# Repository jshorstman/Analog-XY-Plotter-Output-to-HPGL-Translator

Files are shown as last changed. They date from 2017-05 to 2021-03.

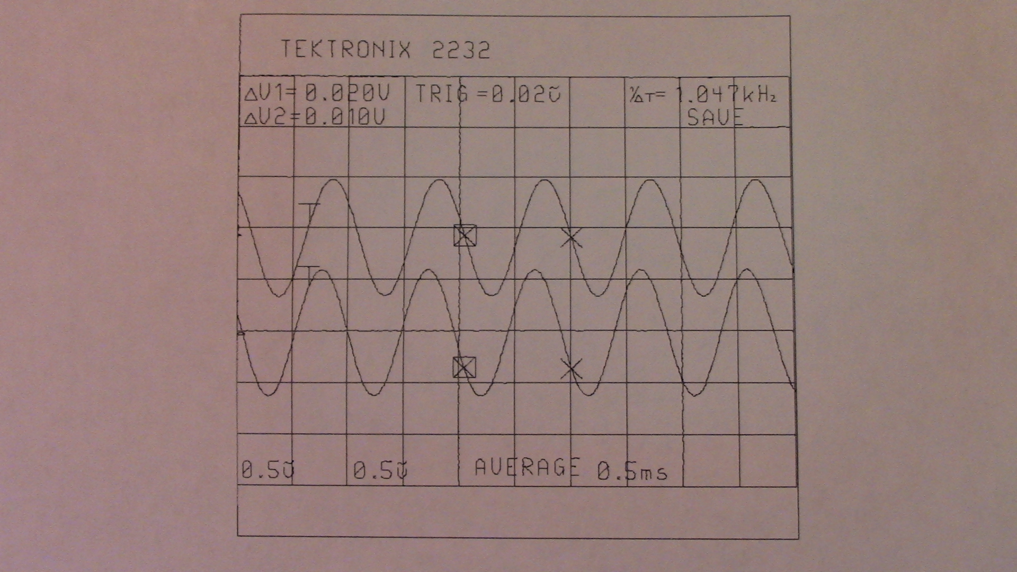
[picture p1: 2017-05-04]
Photos/Sample Plot Printout.JPG

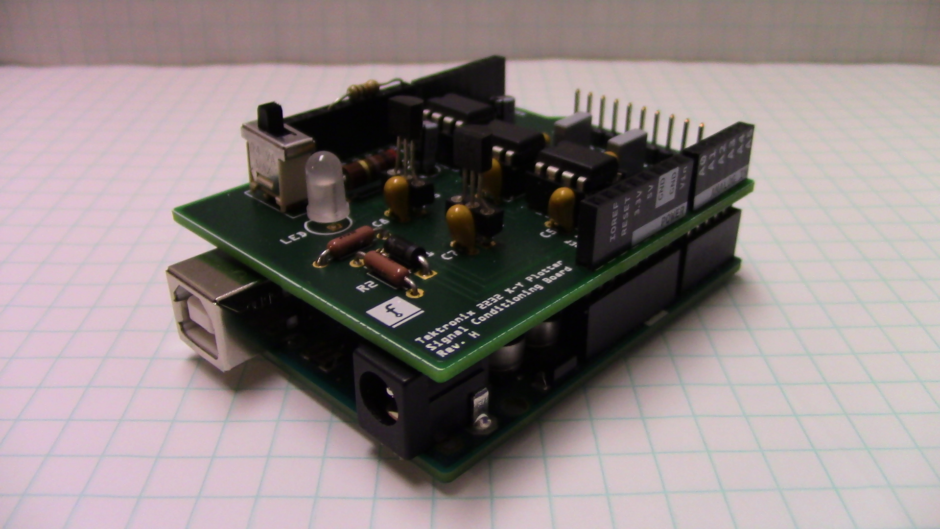
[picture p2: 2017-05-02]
Photos/IMG_0015.JPG

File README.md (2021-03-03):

# Analog-XY-Plotter-Output-to-HPGL-Translator
The Translator will continually sample the X and Y analog voltages from an oscilloscope's pen plotter output port, digitize them, and package the values into a series of plain text HP-GL plotter commands, which are output via a USB port to a file on a PC. The HP-GL file can be processed into a display image by any commonly available plotter emulator application, such as SPLOT (http://www.swplot.com/splot.htm).<BR>
Read all about it in the 'Documentation/Translator Description.docx' document.<BR>
See the demo video on YouTube; https://youtu.be/DhNy6BU84X4

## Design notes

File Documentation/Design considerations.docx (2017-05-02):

Purpose:

Convert the analog voltage X-Y pen plotter output of the Tektronix 2232 oscilloscope to a series of HP-GL plotter graphics commands that are serailly output, via USB, to a PC file. The HPGL file can be processed by any print capturing application (like PrintCapture (http://www.printcapture.com/)) and displayed as a plot image.

(HP-GL: Hewlett-Packard Graphics Language (http://en.wikipedia.org/wiki/HPGL))

Subsystems:

1. Arduino UNO (https://www.arduino.cc/en/Main/ArduinoBoardUno) for the ADC conversions, digital filtering, assembly of HPGL commands and serial output.
2. Arduino Proto Shield (https://store.arduino.cc/usa/arduino/arduino-shields/proto-shield-rev3-uno-size) board for signal conditioning (voltage translation), voltage reference and power monitoring.

Design considerations:

1. Use Arduino UNO because it's the most common beginners model and can support an Arduino Proto Shield.
2. Power. The 5V voltage reference, and the summing amps, which output up to 5 volts, require at least 2 volts headroom. Therefore, cannot rely on the USB port as power source. Use 9V external walwart which gives plenty of headroom since this power supply, when plugged in, will also provide power to the Arduino board.
3. Scope outputs ±2.5 volts on X and Y. Arduino UNO analog pins accept only 0 to 5 volts. Need to translate ±2.5v to 0-5v. Use Unity gain summing amplifiers with a 2.5V voltage reference.
4. Need an indication that there is not sufficent power should an external power supply not be used. These ICs cannot operate on ~5V USB power. Add a bi-color red/green LED as a 'Go-No Go' indicator of sufficient power. A voltage divider network to divide 9V power down to 5V for Arduino analog input pin. Also, need schottky protection diode to proect Arduino pin for power supplies over 9 volts.
5. Summing amps must provide down to 0 volts (gnd). Too close to the rail for single-sided powered amps. Need bi-polar power, say ±9V. Use charge pump voltage converter to create -9 volts for the summing amps. Plenty of headroom. Minimum parts count; 2 caps.
6. Current draw from two summing amps will drag down the negative voltage of the voltage converter. Calculation shows voltage dragged down to ~-8.5 volts. Plenty of headroom left.
7. Precision 2.5V voltage reference must drive inputs of the two summing amps.
8. Use a precision 5V voltage reference for the Arduino AREF pin. Don't want to rely on Arduino voltage regulator as a reliable voltage reference.
9. A switch to start and stop the data stream. Some HP-GL initialization commands and finalization commands must be output.
10. Of course, power supply bypass caps for all ICs.
11. Measured maximum slew rate of scope plotter voltages is ~3v/sec. Adjust sampling rate accordingly so as not to have too many redundant plot points (current sampling rate is 615 points/sec).
12. Filtering applied dither: The analog X Y voltages of the Tektronix pen plotter output have copious added dither. That's fine for shaking loose the mecanical plotter arms and is filtered out by the mass inertia of the mechanical arms. BUT, the 10-bit ADC can pick up the dithered voltage at any instant in time. How to filter it out. A combination of analog and digital filtering.
  a. Analog: A 0.068µf (found by trial and error) capacitor to ground on the input couples with the 2KΩ output resistance of the analog output amplifier of the scope to produce an RC low pass filter. That attenuates a lot of the high frequency components of the dithered waveform but it can go only so far before image quality is degraded.
  b. Digital: A moving average filter of n=8. This gets rid of the two LSBs of the ADC value since they're considered noise bits anyway. With n=16 it softens the corners too much in the image.
13. Connect Tektronix shield ground to Arduino ground? Nah, signal ground is good enough, avoids ground loops.
14. Copper ground fill on circuit board.

References:

- Atmel ATmega328/P 8-bit AVR Microcontroller Datasheet.
- Arduino Programming Nootebook by Brian W. Evans.
- Arduino Uno Rev3 Schematic
- Tektronix 2232 Digital Storage Oscilloscope User Manual, 070-7066-01
- Tektronix 2232 Digital Storage Oscilloscope Service Manual, 070-7067-01
- The HP-GL/2 and HP RTL Reference Guide, A Handbook for Program Developers, 5961-3526

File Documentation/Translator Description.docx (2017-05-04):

What it is:

An analog X-Y pen plotter output to HP-GL translator. (Hewlett-Packard Graphics Language (http://en.wikipedia.org/wiki/HPGL)

What it does:

Some measurement devices, like the Tektronix 2232 Digital Storage Oscilloscope, have an analog X-Y pen plotter output port so that the display image can be captured to an analog X-Y pen plotter or recorder. See oscilloscope display, below.

The problem is one wishes to capture the display image in digital form onto a modern day personal computer, since analog pen plotters are virtually extinct. PC images can be pasted directly into documents.

The 'Analog X-Y Pen Plotter Output To HP-GL Translator' will continually sample the X and Y analog voltages from the plotter port, digitize them, and package the values into a series of plain text HP-GL plotter commands, which are output via a USB port to a file on a PC. The HP-GL file can be processed into a display image by any commonly available plotter emulator application, such as PrintCapture (http://www.printcapture.com). See actual plot image, below.

What it's made of:

1. Arduino UNO (http://www.arduino.org/products/boards/arduino-uno) for the ADC conversions, digital filtering, assembly of HP-GL commands and serial output.
2. Arduino 'Shield' type board for signal conditioning (voltage translation), voltage reference and power monitoring. See schematic and boards, below.
3. DB9 cable for connection to the oscilloscope plotter port. See Auxiliary Connector, below.
4. USB cable between Arduino UNO and PC.
5. 9VDC AC adapter (a wall wart).

What's on the Arduino shield board:

The Arduino shield board contains circuitry comprised of (see schematic);

1. Two (2) precision, unity-gain differential amplifiers (wired as summing amps) to translate the ±2.5V analog X and Y voltages into 0 to 5V for the Arduino analog pins. U2, U3
2. A 'charge pump' voltage converter to convert 9VDC to ±9VDC to power the amplifiers. U1, C1, C2
3. A precision 2.50V voltage reference to the amplifiers for the voltage translation. U4
4. A precision 5.00V voltage reference to the Arduino AREF pin. U5
5. A voltage divider network so the 9V Vin can be reduced to 5V for the Arduino analog pin. A schottky diode protects the pin if a higher voltage power supply is used. R1, R2, D1
6. A bi-color red/green LED as a Go/No Go indicator that the 9V power supply is connected, or not. The Arduino sketch will stay in the setup() routine until a 9VDC, or greater, power supply is plugged into the Arduino UNO. These IC's cannot run accurately on the USB ~5V power! LED, R3
7. A slide switch to start the data stream and stop it when the plot is completed. S1
8. A pair of capacitors to filter the DAC dithering of the plotter port X and Y voltage signals. C9, C10
9. A 10-pin header for connection to the oscilloscope plotter port. J1

Operation:

1. Slide switch to OFF.
2. Connect Arduino via DB-9 connector to oscilloscope plotter port.
3. Connect Arduino USB to PC. Arduino powers up, LED is red.
4. Connect 9VDC power to Arduino. LED is green.
5. Launch listening application, like TeraTerm or PrintCapture. Ensure your application is set to the Arduino UNO COM port 6, 115200, 8, none, 1.
6. Slide switch to ON. (data stream commences)
7. Immediately press PLOT key on scope.
8. When scope plot completes immediately slide switch to OFF. (data stream halts)
9. Reset Arduino in order to start the next plot.

Example HP-GL (http://en.wikipedia.org/wiki/HP-GL) output to file:

IN;

PS8900,8900;

IP0,0,8900,8900;

SC0,250,0,1023,1;

PU; // Pen Up

SP1;

PA77,984; // Plot Absolute to (77,984)

... // more data points (PA) every 1.6 milliseconds

PD; // Pen Down

PA53,92;

... // more data points (PA) every 1.6 milliseconds

PU;

SP;

IN;

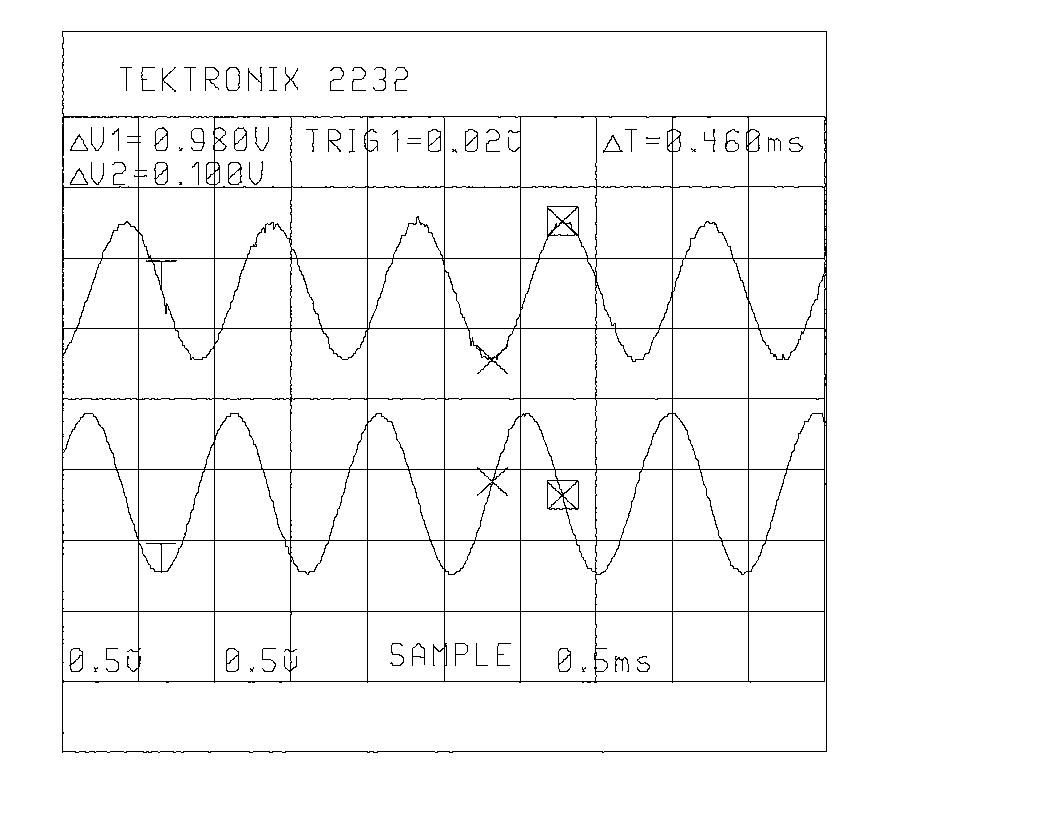
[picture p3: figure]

Actual plot image from an HP-GL file created by the Translator of a Tektronix 2232 oscilloscope display. Image created by PrintCapture (http://www.printcapture.com).

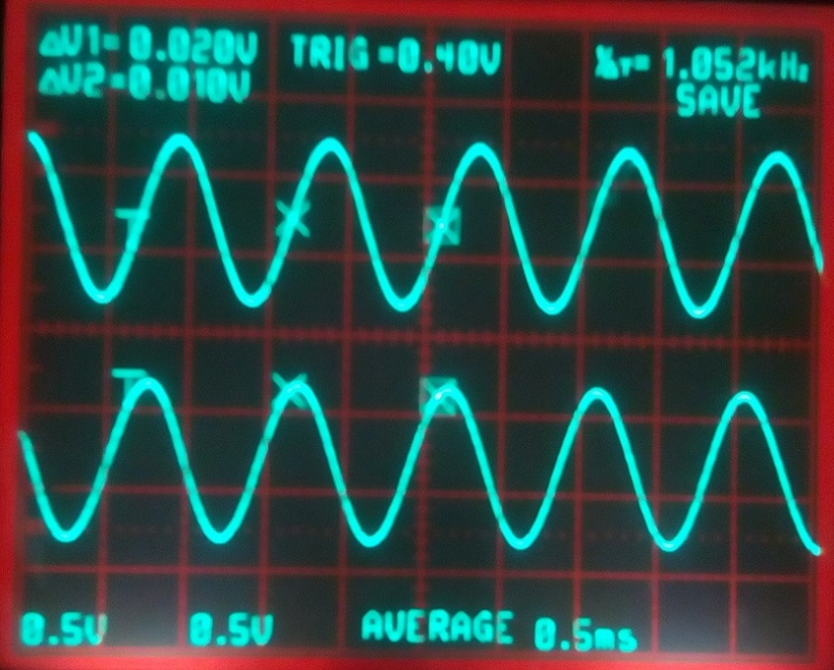
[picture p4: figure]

Actual Tektronix 2232 oscilloscope display.

Schematic:

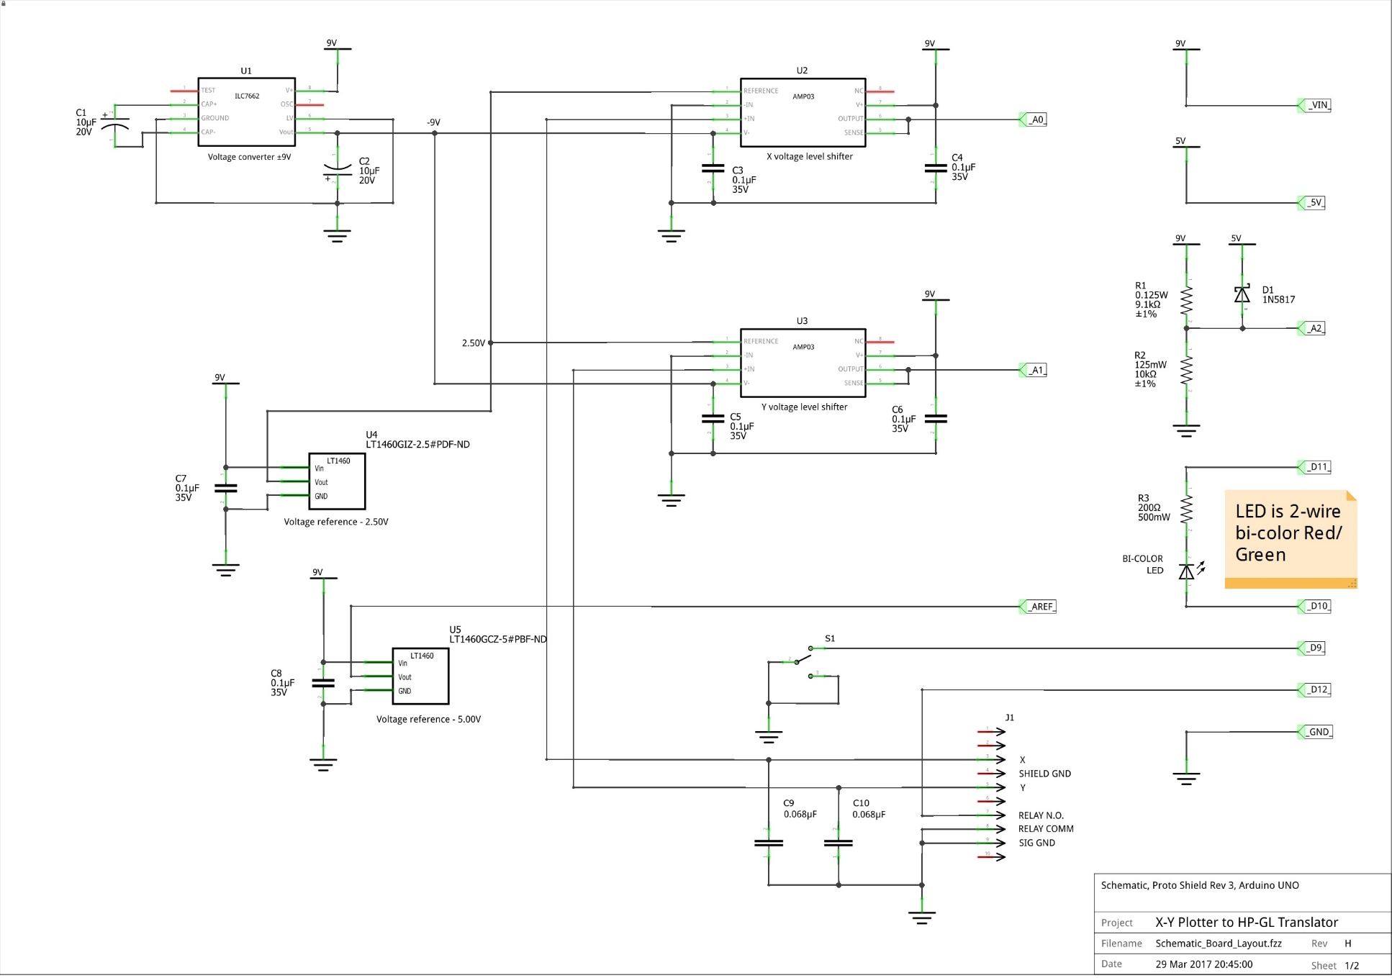
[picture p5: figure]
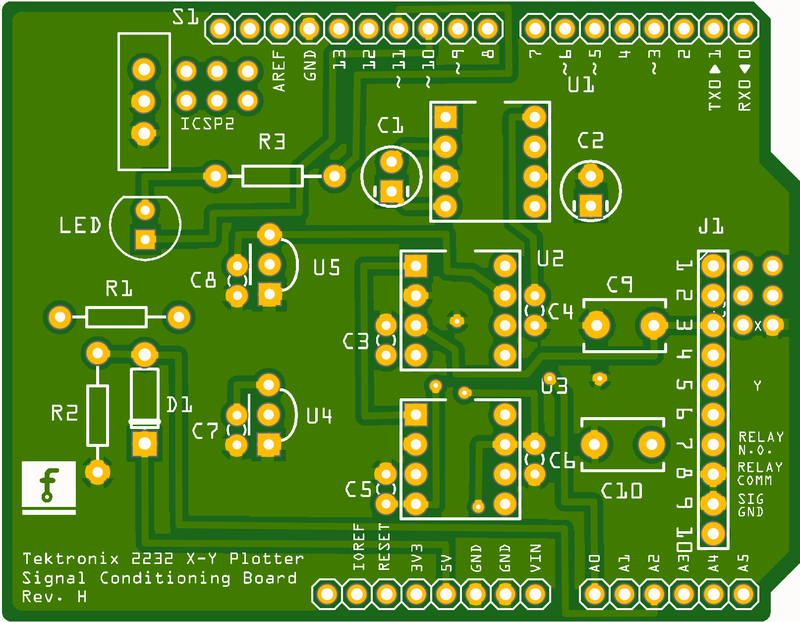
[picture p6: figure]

Arduino shield board front

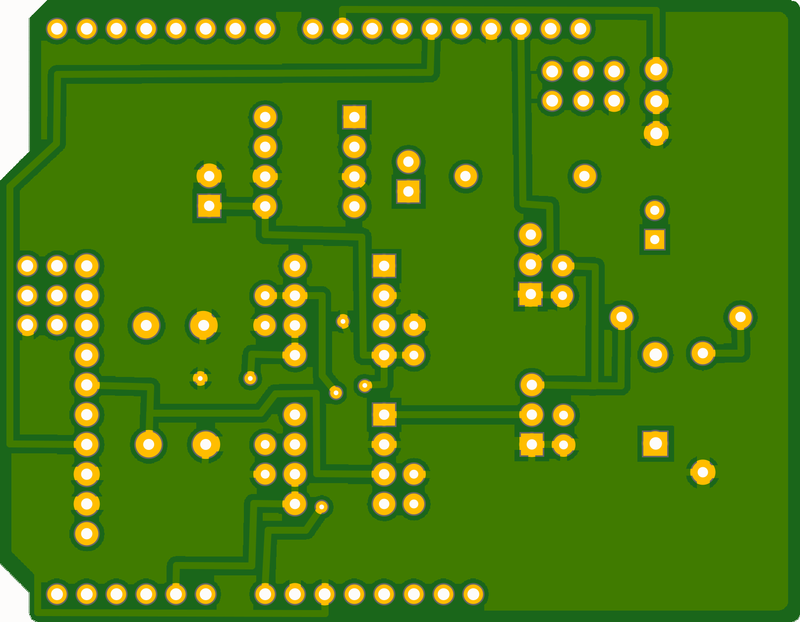
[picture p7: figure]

Arduino shield board back

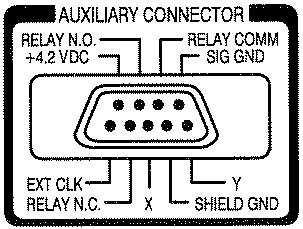
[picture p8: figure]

Tektronix Auxiliary Connector for X-Y plotter. Relay is for pen up/down

Arduino Sketch:

/*

****************************************************************************************|

* Tektronix 2232 Digital Storage Oscilloscope analog X-Y pen plotter to HP-GL

* translator. (Hewlett-Packard Graphics Language http://en.wikipedia.org/wiki/HPGL)

*

* John Horstman

* 3/19/2017 Rev H

*

* This sketch continuously reads the X and Y analog pen plotter voltages, and the

* pen up/down signal, and packages the ADC values in successive HP-GL commands. The

* commands can be serially output to a file, via TeraTerm, or to a plotter application

* like PrintCapture at http://www.printcapture.com/.

*

* The HP-GL commands used in this sketch are:

* IN; Initialize

* PS: Plot size

* IP; Input P1 & P2

* SC; Scale

* SP; Select pen

* PU; Pen UP

* PD; Pen DOWN

* PA; Plot Absolute

*

* Example HPGL output of this sketch:

* IN;

* PS8900,8900;

* IP0,0,8900,8900;

* SC0,250,0,1023,1;

* PU;

* SP1;

* PA77,984;

* ... // data points every 1.6 milliseconds

* PD;

* PA53,92;

* ...

* PU;

* SP;

* IN;

*

* This sketch is for Arduino UNO with Proto Shield. The Proto Shield contains signal

* conditioning circuitry comprised of;

* 1. Two (2) precision, unity-gain differential amplifiers (wired as summing amps)

* to translate the Â±2.5V analog X and Y voltages into 0 to 5V for the Arduino analog

* pins.

* 2. A 'charge pump' voltage converter to convert 9VDC to Â±9VDC to power the amplifiers.

* 3. A precision 2.50V voltage reference to the amplifiers for the voltage translation.

* 4. A precision 5.00V voltage reference to the Arduino AREF pin.

* 5. A voltage divider network so the 9V Vin can be reduced to 5V for the Arduino

* analog pin. A schottky diode protects the pin if a higher voltage power supply

* is used.

* 6. A bi-color red/green LED as a Go/No Go indicator that the 9V power supply

* is connected, or not. This sketch will stay in the setup() routine until a

* 9VDC, or greater, power supply is plugged in to the Arduino. These IC's

* cannot run accurately on the USB ~5V power!

* 7. A slide switch to start the data stream and stop it when the plot is completed.

* 8. A pair of capacitors to filter the DAC dithering of the plotter X-Y voltage signals.

* 9. A 9-pin cable with DB-9 male connector for connection to the oscilloscope plotter

* port.

*

* Operation:

* Slide switch to OFF.

* Connect Arduino via DB-9 connector to oscilloscope plotter port.

* Connect Arduino USB to PC. Arduino powers up, LED is red.

* Connect 9VDC power to Arduino. LED is green.

* Launch listening application, like TeraTerm or PrintCapture. Ensure your application

* is set to the Arduino COM port 6, 115200, 8, none, 1.

* Slide switch to ON. (data stream commences)

* Immediately press PLOT key on scope.

* When scope plot completes immediately slide switch to OFF. (data stream halts)

* Reset Arduino in order to start the next plot.

****************************************************************************************|

*/

//#define __serial_plotter // uncomment to calibrate with Arduino Serial Plotter tool

//#define __dummy_data // uncomment to use dummy data for testing

// The pins

#define TestPin 8 // Digital pin 8

#define SwitchPin 9 // Digital pin 9

#define LEDGreenPin 10 // Digital pin 10

#define LEDRedPin 11 // Digital pin 11

#define PenInputPin 12 // Digital pin 12

#define IdleLED 13 // Digital pin 13

#define X_voltage 0 // Analog pin A0

#define Y_voltage 1 // Analog pin A1

#define VinVoltage 2 // Analog pin A2

// The numbers

unsigned long LoopTime; // Marker for loop() delay timer

unsigned int PenState = HIGH; // Default pen up

unsigned int OldPenState = PenState; //

const unsigned int numReadings = 8; // Must be a power of two so we can right shift later

unsigned int Xreadings[numReadings]; // Arrays for computing moving average for smoothing

unsigned int Yreadings[numReadings]; //

unsigned int Xtotal = numReadings * 511; // Arrays will be preloaded

unsigned int Ytotal = Xtotal; //

unsigned int readIndex = 0; //

const unsigned int dcXOffset = 0; //21; // Compensate for any DC offset. Adjust this to get approximately 511,511.

const unsigned int dcYOffset = 0; //23; //

// The strings

String ADCXStr; // ADC X counts string

String ADCYStr; // ADC Y counts string

String CmdStr; // HPGL command string

#ifdef __dummy_data

const float slew = 614.0; // max slew rate is 3.0 volts/second = 614 counts/second (@5 volts = 1023 counts)

const float Freq = (1.0/PI) * (slew / 1023.0); // This frequency sinusoidal will have that slew rate (at the zero crossing)

const float TWO_PI_F = 2.0 * PI * Freq;

#endif

/*

* The Setup ****************************************************************************|

*/

void setup() {

// Set I/O pins

pinMode(TestPin, OUTPUT); // timing test pin

pinMode(IdleLED, OUTPUT);

pinMode(LEDRedPin, OUTPUT);

pinMode(LEDGreenPin, OUTPUT);

pinMode(SwitchPin, INPUT_PULLUP);

pinMode(PenInputPin, INPUT_PULLUP); // Pen signal is from Normally Open (N.O.) relay contacts

analogReference(DEFAULT);

// Set LEDs

digitalWrite(IdleLED, HIGH); // Turn on 'idle' LED

digitalWrite(LEDRedPin, LOW); // Turn red/green LED off

digitalWrite(LEDGreenPin, LOW);

// initialize serial communication:

Serial.begin(115200);

// Check for 9V Vin external power, stay in setup() until 9V supply connected

/*

* Why 900 counts? To gaurantee that a 7.5 VDC±5% power pack will not trigger the

* 'Go' signal under maximal conditions:

* 7.5v+5%; R1Ω-1%; R2Ω+1%; USB 5v-5% (AREF); +3 counts (2 LSB ADC error)

*/

while (analogRead(VinVoltage) < 900) {

digitalWrite(LEDRedPin, HIGH); // Turn LED red (no-go)

digitalWrite(LEDGreenPin, LOW);

delay(100);

} // Wait here until user plugs in a 9VDC, or greater, power supply

// Vin OK, continue

digitalWrite(LEDRedPin, LOW); // Turn LED green (go)

digitalWrite(LEDGreenPin, HIGH);

//Wait here for switch to be switched on (ground the pin)

while (digitalRead(SwitchPin) == HIGH) {

delay(100);

}

// User is ready for data stream, let 'er rip!

analogReference(EXTERNAL); // External precision 5.00V reference

// Preset the averaging arrays

for (int thisReading = 0; thisReading < numReadings; thisReading++) {

Xreadings[thisReading] = 511;

Yreadings[thisReading] = 511;

}

digitalWrite(IdleLED, LOW); // turn off 'idle' LED, transmission will commence (TX LED will light)

// HP-GL plot header commands

Serial.println("IN;"); // Initialize

Serial.println("PS8900,8900;"); // Plot size; A-size

Serial.println("IP0,0,8900,8900;"); // Input Scaling Points P1 & P2; A-size drawing (8.5" x 11", less margins)

Serial.println("SC0,1023,0,1023,1;"); // Scale; Isotropic

//Serial.println("OH;"); // Output hard clip limits

//Serial.println("OP;"); // Output P1 & P2

Serial.println("PU;"); // Pun Up

Serial.println("SP1;"); // Select Pen 1

} // end setup

/*

* The Loop *****************************************************************************|

*/

void loop() {

LoopTime = micros(); // mark loop start

// Read X, Y and Pen signals as close together as possible and compute a moving average for smoothing

Xtotal -= Xreadings[readIndex]; // Subtract an old value from the total

Ytotal -= Yreadings[readIndex]; //

PenState = digitalRead(PenInputPin); // Read pen input; returns HIGH or LOW

Xreadings[readIndex] = analogRead(X_voltage) - dcXOffset; // compensate for dc offset

delayMicroseconds(16); // Delay two ADC clock cycles (there is less 'jitter' on the Y readings than for a one ADC clock cycle dalay, don't ask me why)

Yreadings[readIndex] = analogRead(Y_voltage) - dcYOffset;

Xtotal += Xreadings[readIndex]; // Add the new value to the total

Ytotal += Yreadings[readIndex++]; // Increment readIndex here

readIndex %= numReadings; // Wrap around readIndex here

ADCXStr = Xtotal >> 3; // Total divided by numReadings (and convert to string)

ADCYStr = Ytotal >> 3;

//

// If pen has changed state then output pen command

// Pen UP signal is HIGH (relay open, interanl pull up resistor), pen DOWN is LOW (relay closed to ground)

if (PenState != OldPenState) {

(PenState == HIGH) ? (CmdStr = "PU;") : (CmdStr = "PD;");

OldPenState = PenState; // Remember pen state

Serial.println(CmdStr);

}

#ifdef __dummy_data

// dummy data for now, plot a circle

float t = (float)millis() / 1000.0;

float arg = TWO_PI_F * t;

ADCXStr = int(511.5*cos(arg)+511.5);

ADCYStr = int(511.5*sin(arg)+511.5);

#endif

#ifdef __serial_plotter

int Pen;

(PenState == HIGH) ? Pen = 10 : Pen = 0; // View the Pen up/down signal

CmdStr = "1023 0 " + ADCXStr + " " + ADCYStr + " " + Pen; // 1023 0 prevents autoscaling

#else

// 'Plot Absolute' Ex: PA1023,250;

CmdStr = "PA" + ADCXStr + "," + ADCYStr + ";";

#endif

Serial.println(CmdStr);

// If switch went HIGH, output final commands, stop data stream, the plot is completed, wait here until RESET

if (digitalRead(SwitchPin) == HIGH) {

Serial.println("PU;");

Serial.println("SP;");

Serial.println("IN;");

while (true) { // wait here for RESET

// flash 'idle' LED to indicate need for reset

digitalWrite(IdleLED, HIGH);

delay(200);

digitalWrite(IdleLED, LOW);

delay(300);

}

}

//

/* Wait here for remainder of loop time.

* Full scale plot swing is 1023 counts in 1.667 seconds (5 volt full swing / 3.0 volts/second).

* So, no more than one plot command every 1.630ms is necessary (1.667/1023). ~614 samples/second.

*/

while (micros() - LoopTime < 1630) {;} // wait here for remainder of loop time

// Short (0.250Âµs) output pulse to test loop timing.

PORTB |= B1; PORTB ^= B1; // digitalWrite(TestPin, HIGH); digitalWrite(TestPin, LOW);

} // end loop

Part List:

Cost:

Arduino UNO (http://www.arduino.org/products/boards/arduino-uno) | $25
Arduino Proto Shield (http://www.arduino.org/products/shields/arduino-proto-shield) (needed for the headers only. I spun my own board) | $8
Parts (25) | $57
Board by Aiser (http://go.aisler.net/) (qty 3) | $34 (€31)
Total | $124 (€114)

References:

• Atmel ATmega328/P 8-bit AVR Microcontroller Datasheet.

• Arduino Programming Nootebook by Brian W. Evans.

• Arduino Uno Rev3 Schematic

• Tektronix 2232 Digital Storage Oscilloscope User Manual, 070-7066-01

• Tektronix 2232 Digital Storage Oscilloscope Service Manual, 070-7067-01

• The HP-GL/2 and HP RTL Reference Guide, A Handbook for Program Developers, 5961-3526

Analog X-Y Pen Plotter Output To HP-GL Translator http://github.com/jshorstman/Analog-XY-Plotter-Output-to-HPGL-Translator

Analog X-Y Pen Plotter Output To HP-GL Translator

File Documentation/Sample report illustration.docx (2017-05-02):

Lorem ipsum dolor sit amet, consectetur adipiscing elit. Vestibulum lorem ante, pulvinar sed mauris nec, efficitur pretium nisi. Mauris maximus magna eget consequat consequat. Nulla sit amet tortor sed nisi malesuada pharetra. Nulla vitae nibh libero. Aliquam erat volutpat. Donec fringilla sed velit in laoreet. Suspendisse lorem sapien, pretium at auctor sed, porttitor eget ex. Praesent id semper ligula, ac dignissim quam. Donec scelerisque posuere massa ac efficitur. Donec tristique ante a feugiat lobortis. Fusce at orci vel urna lobortis convallis. In iaculis varius porta.

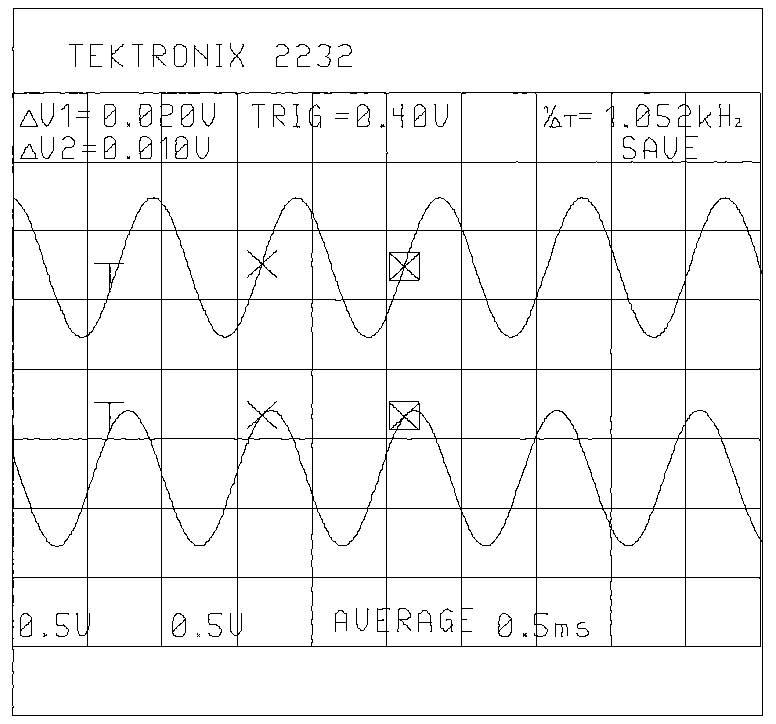
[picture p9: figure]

Interdum et malesuada fames ac ante ipsum primis in faucibus. Sed lorem urna, viverra at viverra vel, eleifend a turpis. Nullam eu nisl venenatis, tempus massa nec, commodo magna. Fusce molestie condimentum sem, eu venenatis lacus maximus a. Donec rutrum metus non mi dignissim tempor. Sed blandit nec lectus sed tincidunt. Donec eleifend erat ac massa porta tristique. Cras ut bibendum ipsum. Proin sagittis purus augue, vel rhoncus purus varius eget. Nunc feugiat elit erat, ut rhoncus lorem rutrum sed. Nulla quis blandit arcu, vel.

Maecenas fringilla malesuada libero, ut lobortis nunc tincidunt sed. Nullam sodales efficitur ligula, sed tincidunt dolor. Mauris venenatis, leo ac sodales vestibulum, leo ante tincidunt dui, sed malesuada nulla lorem nec dolor. Cras lobortis porttitor mollis. Aliquam vehicula odio metus. Sed convallis sit amet purus sed aliquet. Nam nulla orci, viverra non mattis sit amet, eleifend at lacus. Phasellus maximus risus elit. Etiam iaculis quis mauris eget iaculis. Ut risus erat, iaculis non dignissim et, imperdiet porta lectus.

Etiam vitae diam neque. Nam at enim eu nibh dictum ullamcorper. Nam pretium fermentum lectus at cursus. In at sodales metus. Morbi nec lectus id augue consectetur fringilla. Sed dictum est ullamcorper consectetur dignissim. Ut ipsum dolor, efficitur id elit condimentum, vehicula malesuada ipsum. Suspendisse pulvinar ante orci, in ullamcorper mi laoreet id. Vivamus non interdum ligula, sed laoreet justo. In facilisis vehicula mattis. Maecenas lacinia ullamcorper semper.

Aliquam scelerisque nunc vitae mi. 1

Sed id dolor elementum, blandit.

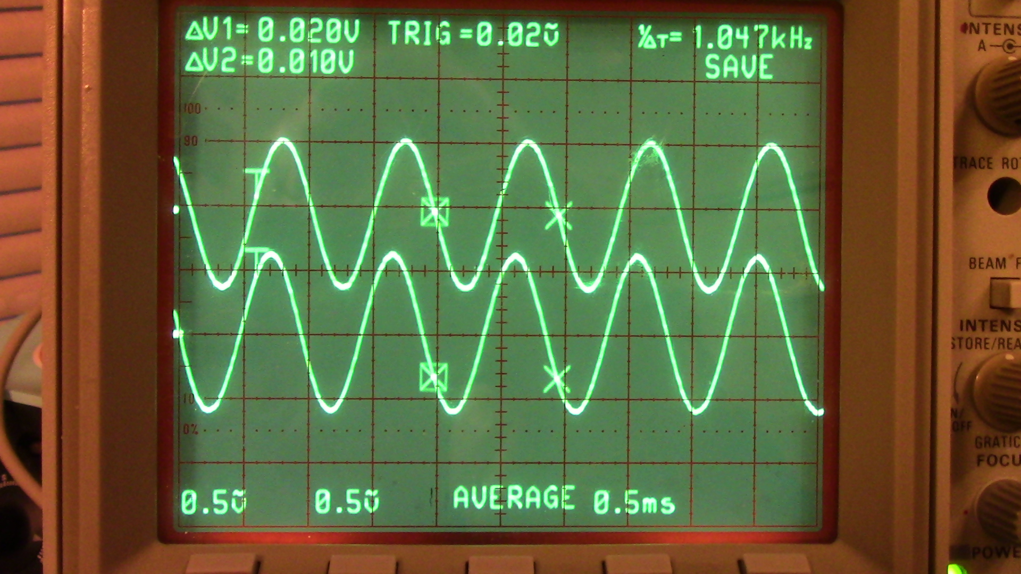
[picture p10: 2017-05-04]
Photos/Actual Scope Trace.JPG

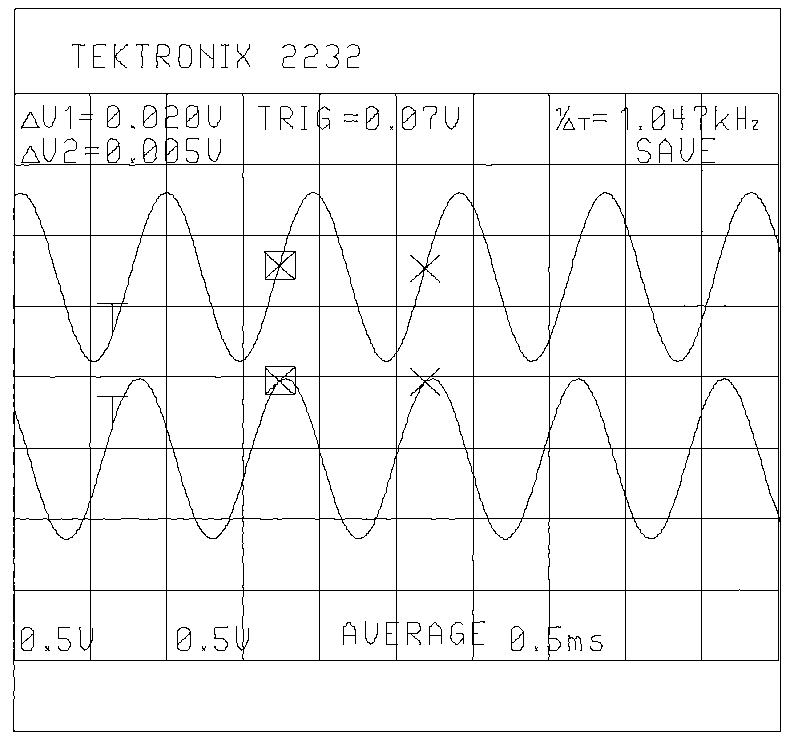
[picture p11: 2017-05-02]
Photos/sample plot.bmp

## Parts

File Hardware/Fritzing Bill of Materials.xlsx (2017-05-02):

project:Tektronix 2232 X-Y Plotter to HPGL Translator file:Signal Conditioning Board - Rev H.fzz
Reference | Quantity | Part Number | Description
C1,C2 | 2 | USR1E100MDD1TP | Aluminum Electrolytic Capacitors - Leaded 10uF 25V 85c 4x7 20% 1.5LS | $0.50
C3,C4,C5,C6,C7,C8 | 6 | TAP104K035SRW | Tantalum Capacitors - Solid Leaded 35volts 0.1uF 10% | $2.76
C9,C10 | 2 | BFC237042682 | CAP FILM 6800PF 5% 250VDC RADIAL | $1.72
D1 | 1 | 1N5817 | DIODE SCHOTTKY 20V 1A DO41 | $0.43
J1 | 1 | 68001-410HLF | CONN HEADER 10POS .100 STR TIN | $0.42
LED | 1 | B4301H1/5 | T1 3/4, 2 Lead, Red/Green LED with Clear Lens Cap Mounting Clip | $1.84
R1 | 1 | RN55D9101FB14 | Metal Film Resistors - Through Hole 1/8watt 9.1Kohms 1% 100ppm | $0.18
R2 | 1 | RN55D1002FB14 | Metal Film Resistors - Through Hole 1/8watt 10Kohms 1% 100ppm | $0.10
R3 | 1 | OF201JE | Carbon Composition Resistors 1/2W 200 ohms 5% | $0.82
S1 | 1 | TS02CBE | Slide Switches Switch Slide Spst Pc Mnt | $4.50
U1 | 1 | ICL7662CPA+ | IC REG SWTCHD CAP INV RATIO 8DIP | $3.54
U2,U3 | 2 | AMP03GPZ | IC OPAMP DIFFERENTIAL 3MHZ 8DIP | $16.02
U4 | 1 | LT1460GIZ-2.5#PBF | IC VREF SERIES 2.5V TO92-3 | $3.27
U5 | 1 | LT1460GCZ-5#PBF | IC VREF SERIES 5V TO92-3 | $3.02
Off board parts
 | Quantity | Part Number | Description
 | 1 | 15388100 | CONN CIC FFC RCPT 10POS 2.54MM | $2.76
 | 1 | 30-9506-99 | CABLE DB9 FEMALE/MALE 6' | $4.25
 | 1 | SWI6-9-N-P5 | AC/DC WALL MOUNT ADAPTER 9V 6W | $10.51
 |  |  |  | $56.64

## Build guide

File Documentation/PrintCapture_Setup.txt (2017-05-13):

PrintCapture configuration:

Menu: Setup->Configuration...

Configuration window:

Serial Port tab:
Port: <your Arduino COM port>
Baud Rate: 115200
Word Size: 8
Parity: None
Stop Bits: 1

Image Processing tab:
Auto Trim: checked
Keep Raw Data: checked
Resolution: 194 DPI*
Print Processing 100%; Portrait

* With a resoution of 194 DPI the one centimeter graticule squares are printed as one centimeter.

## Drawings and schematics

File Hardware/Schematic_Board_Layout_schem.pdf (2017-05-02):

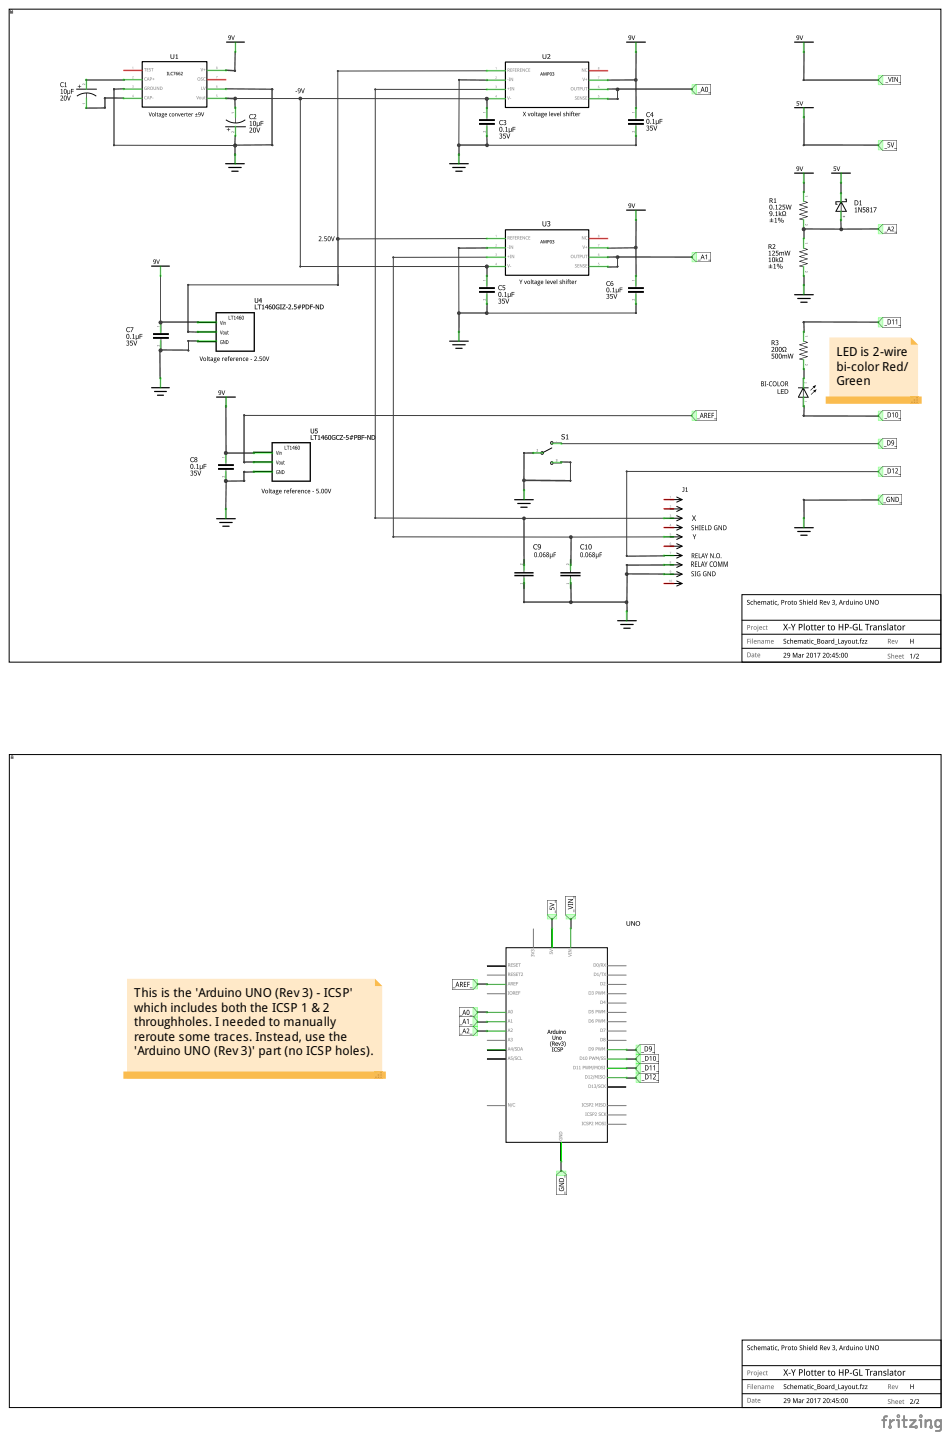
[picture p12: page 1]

LED is 2-wire
bi-color Red/
Green

This is the 'Arduino UNO (Rev 3) - ICSP'
which includes both the ICSP 1 & 2
throughholes. I needed to manually
reroute some traces. Instead, use the
'Arduino UNO (Rev 3)' part (no ICSP holes).

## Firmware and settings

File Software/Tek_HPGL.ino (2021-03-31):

/*****************************************************************************************|
 * Tektronix 2232 Digital Storage Oscilloscope analog X-Y pen plotter to HP-GL 
 * translator. (Hewlett-Packard Graphics Language http://en.wikipedia.org/wiki/HPGL)
 * 
 * John Horstman
 * 3/17/2021 Revision M
 */
 const String REVISION = "M"; // Current revision
 /* 
 * This sketch continuously reads the X and Y analog pen plotter voltages, and the 
 * pen up/down signal, digitizes them and packages the ADC values in successive HP-GL 
 * commands. The commands can be serially output to a file, via TeraTerm, or to a plotter 
 * application like SPLOT.
 *  
 * The HP-GL commands used in this sketch are:
 * CO;  Comment (HP-GL/2 command)
 * IN;  Initialize
 * IP;  Input P1 & P2
 * SC;  Scale
 * SP;  Select pen
 * PW;  Pen width (HP-GL/2 command)
 * PU;  Pen UP
 * PD;  Pen DOWN
 * PA;  Plot Absolute
 * 
 * Example HP-GL output of this sketch (with a few HP-GL/2 commands):
 * CO "Analog X-Y Pen Plotter to HP-GL Translator";
 * CO "Revision K";
 * CO "dcXOffset=20 dcYOffset=22";
 * IN;
 * IP0,0,4000,4000;
 * SC45,1003,53,957,0;
 * PW0.5,1;
 * SP1;
 * PU77,984;PD;  // move pen to initial point and put down pen
 * PA77,984;     // plot point
 * ...           // data points up to every 1.6 milliseconds only while pen is down
 * PU;
 * SP;
 * IN;
 * 
 * This sketch is for Arduino UNO with Proto Shield. The Proto Shield contains signal 
 * conditioning circuitry comprised of;
 * 1. Two (2) precision, unity-gain differential amplifiers (wired as summing amps) 
 *    to translate the ±2.5V analog X and Y voltages into 0 to 5V for the Arduino analog 
 *    pins.
 * 2. A 'charge pump' voltage converter to convert Vin to ±Vin to power the amplifiers.
 * 3. A precision 2.50V voltage reference to the amplifiers for the voltage translation.
 * 4. A precision 5.00V voltage reference to the Arduino AREF pin.
 * 5. A voltage divider network so the Vin can be reduced for the Arduino analog pin. 
 *    A schottky diode protects the pin if a greater than 9V power supply is used.
 * 6. A bi-color red/green LED as a Go/No Go indicator that the 9V power supply
 *    is connected, or not. This sketch will stay in the setup() routine until a 
 *    6.5VDC, or greater, power supply is plugged in to the Arduino. These IC's 
 *    cannot run accurately on the USB ~5V power!
 * 7. A slide switch to start the data stream and stop it when the plot is completed.
 * 8. A pair of capacitors to filter the DAC dithering of the plotter X-Y voltage signals.
 * 9. A 9-pin cable with DB-9 male connector for connection to the oscilloscope plotter 
 *    port.
 *    
 * Circuit board found here, released under the 
 * 'Creative Commons Attribution-ShareAlike 4.0 International' license
 * (http://creativecommons.org/licenses/by-sa/4.0/):
 * https://aisler.net/PatrickFranken/signal-conditioning-board-rev-h/tektronix-2232-x-y-plotter-to-hpgl-translator
 * 
 * -- Normal Operation: --
 * Slide switch to OFF.
 * Connect Arduino via DB-9 connector to oscilloscope plotter port. 
 * Connect Arduino USB to PC. Arduino powers up, LED is red.
 * Connect power supply (6.5 to 20V) to Arduino. LED is green.
 * Launch listening application, like TeraTerm or PrintCapture. Ensure your application 
 *  is set to the Arduino COM port, 115200, 8, none, 1.
 * Slide switch to ON. (data stream commences)
 * Immediately press 'Start' key on scope's Plot screen.
 * When scope plot completes immediately slide switch to OFF. (data stream halts)
 * Reset Arduino in order to start the next plot.
 *
 * -- Auto Center and Auto Scaling Operation: --
 * Tie Pin 7 to ground.
 * Setup per Normal Operation.
 * Except, press the 'XY Setup' button on scope's Plot screen.
 * When scope draws the outer box slide switch to OFF.
 * Remove Pin 7 from ground. (values are now in EEPROM)
 * Reset Arduino in order to start a plot in Normal Operation.
 * 
 *****************
 * The MIT License
 *****************
 * https://opensource.org/licenses/MIT
 * Copyright (c) 2017 John Horstman
 * 
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
NTRACT, TORT OR OTHERWISE, ARISING FROM,
 * OUT OF OR IN CONNECTION WITH THE SOFTWARE OR THE USE OR OTHER DEALINGS IN THE
 * SOFTWARE.
 *****************
 * 
 * Open source here:
 * https://github.com/jshorstman/Analog-XY-Plotter-Output-to-HPGL-Translator
 *****************************************************************************************/
//https://playground.arduino.cc/Code/Timer1/
#include <TimerOne.h>
#include <EEPROM.h>
//#define __dummy_data // uncomment to use dummy data for testing
//#define __serial_plotter // uncomment to calibrate with Arduino Serial Plotter tool

// The pins
#define PlotSetupPin 7 // Digital pin 7
#define TestPin 8      // Digital pin 8
#define SwitchPin 9    // Digital pin 9
#define LEDGreenPin 10 // Digital pin 10
#define LEDRedPin 11   // Digital pin 11
#define PenInputPin 12 // Digital pin 12
#define IdleLED LED_BUILTIN // Digital pin 13
#define X_voltage 0    // Analog pin A0
#define Y_voltage 1    // Analog pin A1
#define VinVoltage 2   // Analog pin A2
// The logic levels
#define DOWN LOW
#define UP HIGH
#define NO_GO LOW
#define GO HIGH
#define OFF LOW
#define ON HIGH
// The inlines
#define IdleLED_(x) digitalWrite(IdleLED, x)
// The numbers
#define numReadings 8              // Must be a power of 2 so we can right shift later
#define divisor 3                  // Must be the integer exponent on 2 to get numReadings
#define eeSCAddressBase 0          // EEPROM base address for storing SC command values
#define eeCEAddressBase 8          // EEPROM base address for storing DC offset values
int PenState = UP;                 // Default pen up
int OldPenState = PenState;        //
int Xreadings[numReadings];        // Arrays for computing moving average for smoothing
int Yreadings[numReadings];        //
int Xtotal = numReadings * 511;    // Arrays will be preloaded
int Ytotal = Xtotal;               //
int Xcoor = Xtotal;                //
int Ycoor = Ytotal;                //
int oldXcoor = Xcoor;              //
int oldYcoor = Ycoor;              //
int XCenter = 0;                   // DC offset values during XY Setup
int YCenter = 0;                   //
int MinXExtent = 1024;             // Extent values are computed during XY Setup, initialized here
int MaxXExtent = 0;                //
int MinYExtent = 1024;             //
int MaxYExtent = 0;                //
int eeSCAddress = eeSCAddressBase; // EEPROM address for four SC command values
int eeCEAddress = eeCEAddressBase; // EEPROM address for two dcOffset values
int readIndex = 0;                 // Array index
int dcXOffset = 0;                 // Compensate for any DC offset. Calculated and stored during XY Setup
int dcYOffset = 0;                 //
// The flags
boolean changeFlag = false;            // Set when new XY coordinate differs from previous
boolean PenStateChangeToDown = false;  // Pen state change flag when pen first transitions to down from up
boolean PlotSetupMode = false;         // Flag true if in XY Setup (pin 7 low)
// The strings
String ADCXStr; // ADC X counts string
String ADCYStr; // ADC Y counts string
String CmdStr;  // HPGL command string

#ifdef __dummy_data
const float slew = 614.0; // max slew rate is 3.0 volts/second = 614 counts/second (@5 volts = 1023 counts)
const float Freq = (1.0/PI) * (slew / 1023.0);  // This frequency sinusoidal will have that slew rate (at the zero crossing)
const float TWO_PI_F = TWO_PI * Freq;
#endif

/*
 * The Setup *****************************************************************************|
 */ 
void setup() {
  // Set I/O pins
  pinMode(TestPin, OUTPUT); // timing test pin
  pinMode(IdleLED, OUTPUT);
  pinMode(LEDRedPin, OUTPUT);
  pinMode(LEDGreenPin, OUTPUT);
  pinMode(PlotSetupPin, INPUT_PULLUP);  // used during XYSetup to record XY extent values to EEPROM 
  pinMode(SwitchPin, INPUT_PULLUP);
  pinMode(PenInputPin, INPUT_PULLUP); // Pen signal is from Normally Open (N.O.) relay contacts

  /* For analog input pins, the digital input buffer should be disabled at all times.
   * Atmel-42735B-ATmega328/P_Datasheet_Complete-11/2016 p66
   * Data Input Disable Register 0 (DIDR0)
   * ADC2D, ADC1D and ADC0D set to 1.  p326 */
  bitSet(DIDR0, ADC0D);
  bitSet(DIDR0, ADC1D);
  bitSet(DIDR0, ADC2D);
  
  analogReference(DEFAULT);

  // Set LEDs
  IdleLED_(ON); // Turn on 'idle' LED
  Go_NoGo(NO_GO); // set NO GO LED
  
  // Initialize serial communication:
  /* High baud rate because Serial.println() is in an ISR */
  Serial.begin(115200);
  
  // Initialize Loop timer
  /* Full scale plot swing is 1023 counts in 1.667 seconds 
   * (5 volt full swing / 3.0 volts/second).
   * So, no more than one plot command every 1.630ms is necessary (1.667/1023).
   * ~614 samples/second. */
  Timer1.initialize(1630); // set to 1630 microseconds

  // Delay here for battery voltage to drop when LED first turns on
  delay(200);

  waitForNominalVoltage(); // Wait here until user plugs in a 6.5VDC, or greater, power supply
  // Vin OK, continue

  //Wait here for switch to be switched on (ground the pin)
  while (digitalRead(SwitchPin) == HIGH) {
    waitForNominalVoltage();  // Keep checking voltage until switch is thrown    
    delay(100);
  } 
  // User is ready for data stream and voltage is good, let 'er rip!

  analogReference(EXTERNAL); // External precision 5.00V reference

  // Preset the averaging arrays
  for (int i = 0; i < numReadings; i++) {
    Xreadings[i] = 511;
    Yreadings[i] = 511;
  }
  
  // Decide here if in XY Setup mode
  if (digitalRead(PlotSetupPin) == LOW) {
	  PlotSetupMode = true;
  }
  
  // Do auto center here only during XY Setup
  if (PlotSetupMode) {
	  // take average of numReadings readings
    for (int i = 0; i < numReadings; i++) {
      XCenter += analogRead(X_voltage);
      YCenter += analogRead(Y_voltage);
    }
    XCenter = XCenter >> divisor; // Divide by numReadings
    YCenter = YCenter >> divisor;
    dcXOffset = XCenter - 511;  // offset computed based on how far off center the scope is
    dcYOffset = YCenter - 511;  // offsets can be negative. Therefore, signed integers
	  // Burn offset values to EEPROM
    /* Offsets must be computed prior to computing min and max extents */
    EEPROM.put(eeCEAddress, dcXOffset);
    EEPROM.put(eeCEAddress += sizeof(int), dcYOffset);
    eeCEAddress = eeCEAddressBase; // reset memory pointer
  } // end auto center
  
  // Get offset and extent values from EEPROM
  EEPROM.get(eeCEAddress, dcXOffset);
  EEPROM.get(eeCEAddress += sizeof(int), dcYOffset);
  EEPROM.get(eeSCAddress, MinXExtent);
  EEPROM.get(eeSCAddress += sizeof(int), MaxXExtent);
  EEPROM.get(eeSCAddress += sizeof(int), MinYExtent);
  EEPROM.get(eeSCAddress += sizeof(int), MaxYExtent);
  // ensure values from EEPROM are not garbage
  if ((dcXOffset >= -511 && dcXOffset <= 512) && (dcYOffset >= -511 && dcYOffset < 512)) {
	  // do nothing, values are in range
  } else { // they are garbage, set defaults
	  dcXOffset = 0;
	  dcYOffset = 0;
  }
  if ((MinXExtent >= 0 && MinXExtent < 1024) && (MaxXExtent > 0 && MaxXExtent < 1024) && (MinYExtent >= 0 && MinYExtent < 1024) && (MaxYExtent > 0 && MaxYExtent < 1024)) {
    // do nothing, values are in range
  } else { // they are garbage, set defaults
    MinXExtent = 0;
    MaxXExtent = 1023;
    MinYExtent = 0;
    MaxYExtent = 1023;
  } 
  // end getting values
  
  IdleLED_(OFF); // turn off 'idle' LED, transmission will commence (TX LED will light)

  // HP-GL plot header commands
  Serial.println("CO \"Analog X-Y Pen Plotter to HP-GL Translator\";"); // (COmment is an HP-GL/2 command)
  Serial.println("CO \"Revision " + REVISION + "\";");
  Serial.println("CO \"dcXOffset=" + String(dcXOffset) + " dcYOffset=" + String(dcYOffset) + "\";"); // output for convenience
  Serial.println("IN;"); // INitialize
  Serial.println("IP0,0,4000,4000;"); // Input scaling Points P1 & P2; 4000pu=10cm
  Serial.println("SC" + String(MinXExtent) + "," + String(MaxXExtent) + "," + String(MinYExtent) + "," + String(MaxYExtent) + ",0;");  // SCale, anisotropic
  Serial.println("PW0.5,1;"); // Pen 1 Width 0.5mm (HP-GL/2 command)
  Serial.println("SP1;"); // Select Pen 1, black

  // Initialize values if in XY Setup. New values will be computed in Process().
  if(PlotSetupMode) {
    MinXExtent = 1024;
    MaxXExtent = 0;
    MinYExtent = 1024;
    MaxYExtent = 0;
  }
  
  Timer1.attachInterrupt(Process); // ISR
} // end setup

/*
 * The Loop ******************************************************************************|
 */
void loop() {  
  /* If switch went HIGH, output final commands, stop data stream, the plot is 
   * completed, wait here until RESET */
  if (digitalRead(SwitchPin) == HIGH) {
    Timer1.detachInterrupt(); //stop the timer interrupt
    Serial.println("PU;");
    Serial.println("SP;");
    Serial.println("IN;");
	
	  // Burn scaling values to EEPROM during XY Setup
    /* MaxXExtent-MinXExtent represents the 10cm X-axis span of the scope plot.
     * So, scaling that extent to the 10cm (4000pu) Input Scaling results in a 1:1 scale plot */
    if (PlotSetupMode) {
	  eeSCAddress = eeSCAddressBase; // reset memory pointer
	  EEPROM.put(eeSCAddress, MinXExtent);
	  EEPROM.put(eeSCAddress += sizeof(int), MaxXExtent);
	  EEPROM.put(eeSCAddress += sizeof(int), MinYExtent);
	  EEPROM.put(eeSCAddress += sizeof(int), MaxYExtent);
    }

    while (true) {  // wait here for RESET
      // flash 'idle' LED to indicate need for reset
      IdleLED_(ON);
      delay(200);
      IdleLED_(OFF);
      delay(300);
    }
  }
} // end loop

/*
 * The Process ***************************************************************************|
 */ 
// This ISR takes up to 760 µs to complete with two analogRead's and one Serial.println()
void Process(){ 
  // rising edge of timing test pulse.
  PORTB |= B1; // digitalWrite(TestPin, HIGH)
  
#ifdef __dummy_data
  // dummy data for now, plot a circle 
  float t = (float)millis() / 1000.0;
  float arg = TWO_PI_F * t;
  Xcoor = int(511.5*cos(arg)+511.5);
  Ycoor = int(511.5*sin(arg)+511.5);
  (random(1, 1001) == 1L) ? (PenState = UP) : (PenState = DOWN); // Pen up, sometimes
#else
  /* Read X, Y and Pen signals as close together as possible and compute a moving 
   * average for smoothing */
  Xtotal -= Xreadings[readIndex]; // Subtract an old value from the total
  Ytotal -= Yreadings[readIndex]; //
  
  PenState = digitalRead(PenInputPin); // Read pen input; returns HIGH or LOW
  Xreadings[readIndex] = analogRead(X_voltage); // no delay between readings
  Yreadings[readIndex] = analogRead(Y_voltage) - dcYOffset;
  Xreadings[readIndex] -= dcXOffset; // compensate for dc offset here
  
  Xtotal += Xreadings[readIndex];   // Add the new value to the total
  Ytotal += Yreadings[readIndex++]; // Increment readIndex here
  readIndex %= numReadings;  // Wrap around readIndex here

  Xcoor = Xtotal >> divisor; // Divide by numReadings
  Ycoor = Ytotal >> divisor;
  // End read X, Y and pen
#endif

  /* If pen has changed state then set state change flag
   * Pen UP signal is HIGH (relay open, internal pull up resistor), pen DOWN is LOW 
   * (relay closed to ground) */   
  if (PenState != OldPenState) {
    (PenState == DOWN) ? (PenStateChangeToDown = true) : (PenStateChangeToDown = false);    
    OldPenState = PenState; // Remember pen state
  }

  /* Determine if the new Xtotal and Ytotal are different from the old values. If so, 
   * output the new plot point (set changeFlag). */
  if (Xcoor != oldXcoor) {
    ADCXStr = Xcoor;
    oldXcoor = Xcoor;
    changeFlag = true;
	  if (PlotSetupMode) {
	    if (Xcoor > MaxXExtent) {MaxXExtent = Xcoor;} // used only for XY Setup
	    if (Xcoor < MinXExtent) {MinXExtent = Xcoor;}
	  }
  } 
  if (Ycoor != oldYcoor) {
    ADCYStr = Ycoor;
    oldYcoor = Ycoor;
    changeFlag = true;
    if (PlotSetupMode) {
	    if (Ycoor > MaxYExtent) {MaxYExtent = Ycoor;}
	    if (Ycoor < MinYExtent) {MinYExtent = Ycoor;}
	  }
  } 
  
  // 'Plot Absolute' Ex: PA1023,250;
  // Or, 'Pen Up' move and 'Pen Down'  Ex: PU1023,250;PD;
  if (changeFlag) {
#ifdef __serial_plotter
    CmdStr = "1023 0 " + ADCXStr + " " + ADCYStr; // 1023 0 prevents autoscaling 
#else
    /* When the pen transitions to down from up, output the PU command to move the pen
     * to the new location, then output the PD command. */
    if (PenStateChangeToDown)  {  // pen has just gone down 
      CmdStr = "PU" + ADCXStr + "," + ADCYStr + ";" + "PD;";
      PenStateChangeToDown = false; // do this only once for every pen down transition
    } else {  // else it's a bona fide plot command
	    CmdStr = "PA" + ADCXStr + "," + ADCYStr + ";";
  	}
#endif
    if (PenState == DOWN) {  // plot only when pen down
      // We can afford only one Serial.println so as not to violate our ISR timing.
      Serial.println(CmdStr);
    }
    changeFlag = false;  // don't plot again until the coordinate(s) change
  }
  
  // falling edge of timing test pulse.
  PORTB ^= B1; // digitalWrite(TestPin, LOW);
} // end Process

/*
 * The Functions *************************************************************************|
 */ 
void waitForNominalVoltage(void) {
 /* Check for external power, stay in setup() until >6.5V supply connected
  * 6.5V external supply is 6.3V Vin (due to diode drop on Arduino UNO board)
  * 6.3V is the absolute minimum supply for the op-amps, U2 & U3, and the 5V voltage reference, U5
  * 6.3V through the resistor divider network, R1 & R2, is 3.3V
  * 3.3V, with 5V AREF, is 675 ADC counts (3.3 / 5 * 1023) */
  while (analogRead(VinVoltage) < 675) {
    Go_NoGo(NO_GO); // set NO GO LED
    delay(100);
  } // Wait here until user plugs in a 6.5VDC, or greater, power supply
  Go_NoGo(GO); // set GO LED
} // end waitForNominalVoltage

void Go_NoGo(int state) {
  if (state == GO) {
    digitalWrite(LEDGreenPin, HIGH); // Turn on green LED
    digitalWrite(LEDRedPin, LOW);
  } else {
    digitalWrite(LEDRedPin, HIGH); // Turn on red LED
    digitalWrite(LEDGreenPin, LOW);
  }
} // end Go_NoGo

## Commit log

2017-05-02 Add files via upload
    This is the initial reposit.
    [Fritzing Bill of Materials.xlsx, Schematic_Board_Layout.fzz]
2017-05-02 Add files via upload
    PDF of the Fritzing board.
2017-05-03 Move file to new directory
    [Fritzing Bill of Materials.xlsx, Schematic_Board_Layout.fzz]
2017-09-05 Update LICENSE.txt
    Only my Signal Conditioning Board, and not the Arduino UNO, is subject to the CC License.
2017-09-05 Update LICENSE.txt
    Arduino UNO firmware is not subject to the MIT license.
2021-03-03 Update Tek_HPGL.ino
    //Changes for revision J
    //
    //Little things:
    //1. Create String REVISION for use in HPGL comment command.
    //2. Add HPGL command PW (pen width).
    //3. Add HPGL command CO (comment).
    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
2021-03-10 Add files via upload
    //Changes for revision K
    //1. Set Data Input Disable Register 0.
    //2. Remove delay between analog reads.
    //Big things:
    //3. Supress PA commands while pen is UP as follows:
    // a. When the pen transitions to down from up, output the PU command to move
    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
2021-03-11 Add files via upload
    //Changes for revision L
    //1. Redesign the plumbing so as to only need one call to Serial.println().
    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
    [Tek_HPGL.ino]
2021-03-31 Add files via upload
    Changes for revision M
    BIG things:
    1. Use EEPROM to store centering and scaling information;
    Calcualte and store the dcXoffset and dcYoffset values and the four extent
    values for the SC scale command. This results in the printed plot in 1:1 scale
    (10cmx10cm). With pin 7 low use the XYSetup function of the scope. The values
    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
